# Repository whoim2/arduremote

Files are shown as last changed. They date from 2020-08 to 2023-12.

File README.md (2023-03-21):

# arduremote
ARDU Remote: simple USB / PPM (and SBUS in tests) RC radio controller transmitter 10 channels with QCZEK LRS

### updates:
21/03/2023 8 axes and 2 buttons in usb joystic mode, custom changes in ArduinoJoystickLibrary - download used_libs.zip!

### ВАЖНО:
If the equipment constantly beeps when turned on, this is due to high channel performance protection. You connected something incorrectly, or did not turn off important channels. You can enable SERIAL_DEBUG and evaluate channel values, or disable protection by setting started = true and check values otherwise.

Если аппаратура постоянно пищит при включении, это срабатывает защита от высоких показателей каналов. Вы что то подключили неправильно, или не выключили важные каналы. Вы можете включить SERIAL_DEBUG и оценить значения каналов, или отключить защиту установив started = true, и проверить значения иначе.

Based on arduino pro micro (atmega32u4), have h/w USB port for use as joystic in any OS.
Work with Open.HD.
Have simple calibrate procedure.
Have start protection and 30-secs warning if not used.

May work with QCZEK LRS and other, have PPM pin 8/10 channels.

QCZEK Project: http://qczek.beyondrc.com/qczek-lrs-433mhz-1w-lora-rc-link/

Low cost RC controller from old RC parts! 3D models present.



If you want use this only as usb joystic, you not need battery, power module, power switch and not need remove fuse on Arduino Pro Micro.
If you use PPM and LRS, you need set channels count in PPMEncoder.h to 10

=== SBUS TEST VERSION ===

QCZEK >=2.0 have only SBUS input. Try this sketch for it: https://github.com/whoim2/arduremote/blob/SBUS-test/ardu_remote.ino
Not need external inverter, but need resistors for down voltage from 5v to 3.3v. As for ppm pin on sheme. Connect TX pin arduino to RX pin qczek via resistors.

===

Video for russian users: https://youtu.be/x-7y0d95x8k
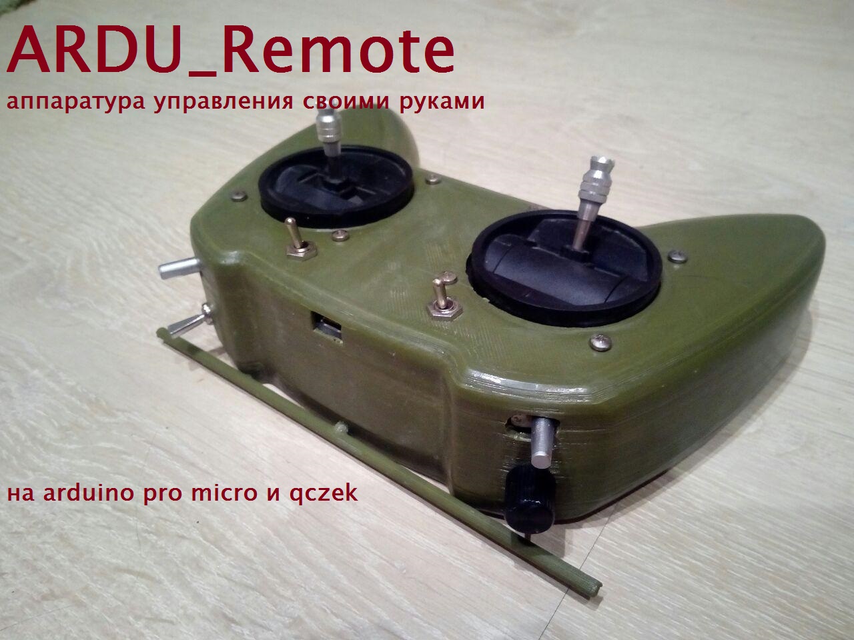
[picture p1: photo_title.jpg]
Watch the video (https://youtu.be/x-7y0d95x8k)


===

Build:
1) install Arduino IDE
2) copy folders from used_libs.zip to Arduino/libraries folder
3) open ardu_remote.ino in Arduino IDE, try to compile
4) connect Arduino Pro Micro to usb
5) select pro micro in tools/boards menu, press Upload button in IDE
6) solder all parts to Arduino, using sheme.bmp

===

For calibrate sticks & aux1, press calibrate button and power on, before set roll/pitch/yaw axis in zero position, trottle & aux1 set to minimum. While beeps, move sticks & aux1 from min to max positions.
If no beeps at time, power off device. Calibrate done.

Short beeps after power on - protection, channels value not in minimum. Off all switchs & move throttle to minimum.

===

You may connect jdy-30 / hc-05/06 bluetooth module to qczek and have mavlink telemetry on android device with "Droid Planner 2.8" or "Telemetry Vieawer" app. It work with Inav / mavlink.

Also, you may connect mavlink-display to QCZEK:
https://github.com/whoim2/mavlink-display

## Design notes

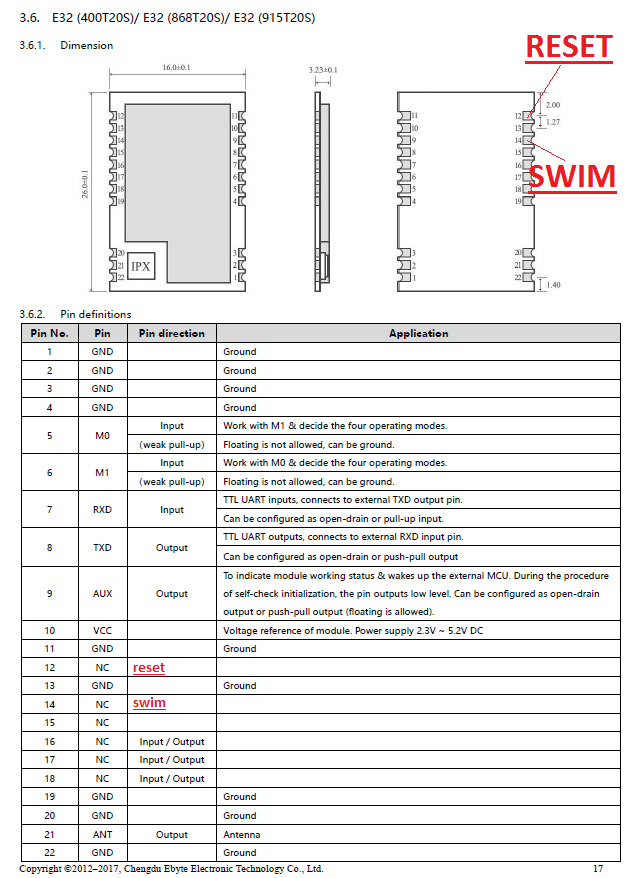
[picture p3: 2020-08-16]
915T20S.PNG

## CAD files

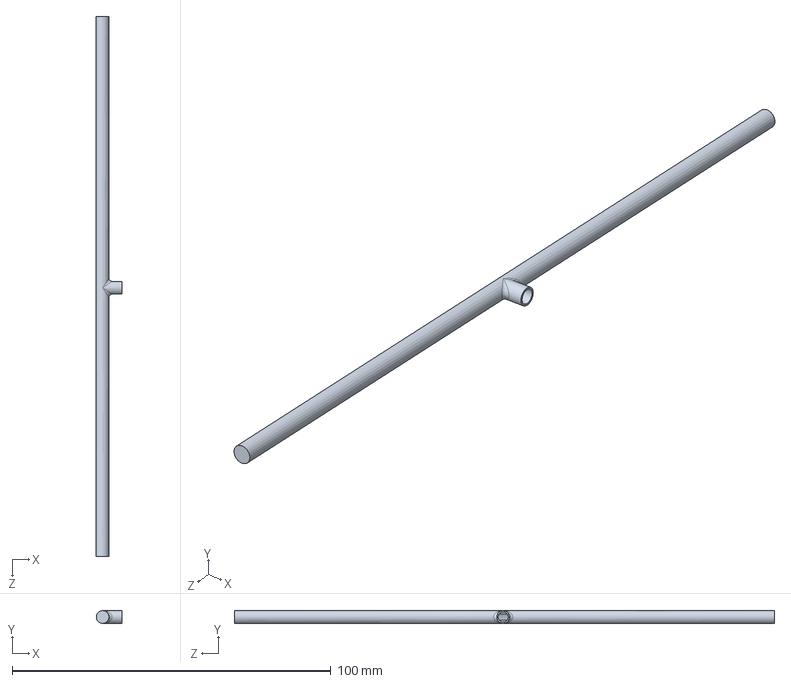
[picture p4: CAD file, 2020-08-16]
ant_868_full.SLDPRT
8.00 x 4.00 x 169.3 mm

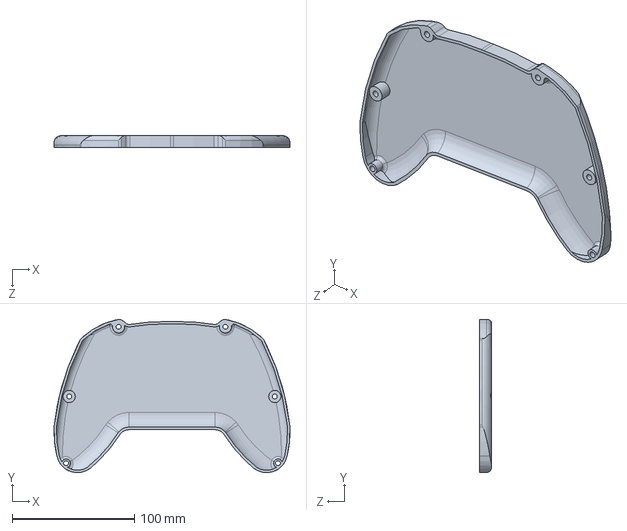
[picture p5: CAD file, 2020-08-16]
bottom.SLDPRT
193.2 x 125.4 x 10.0 mm

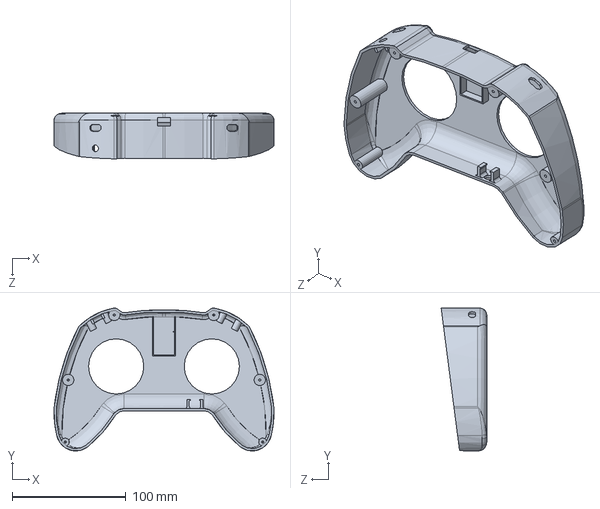
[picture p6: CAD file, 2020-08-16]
top.SLDPRT
193.2 x 125.4 x 40.0 mm

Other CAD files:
ant_868_full.STL
bottom.STL
top.STL

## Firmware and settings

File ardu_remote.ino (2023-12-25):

/* 
 ARDU_REMOTE
 usb / ppm simple remote
 whoim@mail.ru
*/

#include <EEPROM.h>
#include <JoystickMHX.h>
#include "PPMEncoder.h"

Joystick_ Joystick(JOYSTICK_DEFAULT_REPORT_ID,JOYSTICK_TYPE_JOYSTICK,
  32, 2,                  // Button Count, Hat Switch Count
  true, true, true,     // X and Y, Z Axis
  true, true, true,   // Rx, Ry,  Rz
  true, true, true, true,  // slider, dial, rudder and throttle
  false, false, false);  // accelerator, brake, and steering

//uncomment this for see states in port monitor, 9600bps
//usb joystic not work, comment for usb mode
//#define SERIAL_DEBUG

#define TRTL_PIN          A2
#define YAW_PIN           A3
#define PITCH_PIN         A1
#define ROLL_PIN          A0
#define SW1_PIN           6
#define SW2_PIN           4
#define SW3_1_PIN         7
#define SW3_2_PIN         8
#define SW4_PIN           16  //comment to disable
#define SW5_PIN           14  //comment to disable
#define AUX1_PIN          A10 //comment to disable

//
#define BUZZER_PIN        3
#define LED_PIN           2
#define SW_CALIBRATE_PIN  5

//PPM output, comment to disable
//#define PPM_PIN 9

//SBUS output, comment to disable (tx pin of serial)
//#define SBUS

//UART output for jdy-40/41
#define UART

//non-use beep timer millis, comment to disable
//#define NTIM 30000


// sbus settings
#define RC_CHANNEL_MIN 990
#define RC_CHANNEL_MAX 2010

#define SBUS_MIN_OFFSET 173
#define SBUS_MID_OFFSET 992
#define SBUS_MAX_OFFSET 1811
#define SBUS_CHANNEL_NUMBER 16
#define SBUS_PACKET_LENGTH 25
#define SBUS_FRAME_HEADER 0x0f
#define SBUS_FRAME_FOOTER 0x00
#define SBUS_FRAME_FOOTER_V2 0x04
#define SBUS_STATE_FAILSAFE 0x08
#define SBUS_STATE_SIGNALLOSS 0x04
#define SBUS_UPDATE_RATE 10 //ms

//
#define UART_UPDATE_RATE 20 //ms

//sketch
bool started = false;

//calibrate vars
int rollmax, rollmin, rollzero;
int pitchmax, pitchmin, pitchzero;
int yawmax, yawmin, yawzero;
int throttlemax, throttlemin;
#ifdef AUX1_PIN
int aux1max,aux1min;
#endif
uint32_t joyTime = 0;
#define JOY_UPDATE_RATE 15 //ms

uint8_t ch13_val = 0;
uint8_t ch14_val = 0;
uint8_t ch15_val = 0;

#ifdef NTIM
uint32_t prevtimer = millis();
int16_t prev_ch_crc;
#endif

#ifdef SBUS
uint8_t sbusPacket[SBUS_PACKET_LENGTH];
int rcChannels[SBUS_CHANNEL_NUMBER];
uint32_t sbusTime = 0;
#endif

#ifdef UART
uint32_t uartTime = 0;
#endif

//********* FUNCTIONS ***********
void EEPROM_int_write(int addr, int num) {
  byte raw[2];
  (int&)raw = num;
  for(byte i = 0; i < 2; i++) EEPROM.write(addr+i, raw[i]);
}
int EEPROM_int_read(int addr) {    
  byte raw[2];
  for(byte i = 0; i < 2; i++) raw[i] = EEPROM.read(addr+i);
  int &num = (int&)raw;
  return num;
}

void beep(uint16_t time) {
  digitalWrite(LED_PIN, LOW);
  tone(BUZZER_PIN, 1000);
  delay(time / 10);
  noTone(BUZZER_PIN);
  digitalWrite(LED_PIN, HIGH);
}

//sbus functions
void sbusPreparePacket(uint8_t packet[], int channels[], bool isSignalLoss, bool isFailsafe){

    static int output[SBUS_CHANNEL_NUMBER] = {0};

    /*
     * Map 1000-2000 with middle at 1500 chanel values to
     * 173-1811 with middle at 992 S.BUS protocol requires
     */
    for (uint8_t i = 0; i < SBUS_CHANNEL_NUMBER; i++) {
        output[i] = map(channels[i], RC_CHANNEL_MIN, RC_CHANNEL_MAX, SBUS_MIN_OFFSET, SBUS_MAX_OFFSET);
    }

    uint8_t stateByte = 0x00;
    if (isSignalLoss) {
        stateByte |= SBUS_STATE_SIGNALLOSS;
    }
    if (isFailsafe) {
        stateByte |= SBUS_STATE_FAILSAFE;
    }
    packet[0] = SBUS_FRAME_HEADER; //Header 

    packet[1] = (uint8_t) (output[0] & 0x07FF);
    packet[2] = (uint8_t) ((output[0] & 0x07FF)>>8 | (output[1] & 0x07FF)<<3);
    packet[3] = (uint8_t) ((output[1] & 0x07FF)>>5 | (output[2] & 0x07FF)<<6);
    packet[4] = (uint8_t) ((output[2] & 0x07FF)>>2);
    packet[5] = (uint8_t) ((output[2] & 0x07FF)>>10 | (output[3] & 0x07FF)<<1);
    packet[6] = (uint8_t) ((output[3] & 0x07FF)>>7 | (output[4] & 0x07FF)<<4);
    packet[7] = (uint8_t) ((output[4] & 0x07FF)>>4 | (output[5] & 0x07FF)<<7);
    packet[8] = (uint8_t) ((output[5] & 0x07FF)>>1);
    packet[9] = (uint8_t) ((output[5] & 0x07FF)>>9 | (output[6] & 0x07FF)<<2);
    packet[10] = (uint8_t) ((output[6] & 0x07FF)>>6 | (output[7] & 0x07FF)<<5);
    packet[11] = (uint8_t) ((output[7] & 0x07FF)>>3);
    packet[12] = (uint8_t) ((output[8] & 0x07FF));
    packet[13] = (uint8_t) ((output[8] & 0x07FF)>>8 | (output[9] & 0x07FF)<<3);
    packet[14] = (uint8_t) ((output[9] & 0x07FF)>>5 | (output[10] & 0x07FF)<<6);  
    packet[15] = (uint8_t) ((output[10] & 0x07FF)>>2);
    packet[16] = (uint8_t) ((output[10] & 0x07FF)>>10 | (output[11] & 0x07FF)<<1);
    packet[17] = (uint8_t) ((output[11] & 0x07FF)>>7 | (output[12] & 0x07FF)<<4);
    packet[18] = (uint8_t) ((output[12] & 0x07FF)>>4 | (output[13] & 0x07FF)<<7);
    packet[19] = (uint8_t) ((output[13] & 0x07FF)>>1);
    packet[20] = (uint8_t) ((output[13] & 0x07FF)>>9 | (output[14] & 0x07FF)<<2);
    packet[21] = (uint8_t) ((output[14] & 0x07FF)>>6 | (output[15] & 0x07FF)<<5);
    packet[22] = (uint8_t) ((output[15] & 0x07FF)>>3);

    packet[23] = stateByte; //Flags byte
    packet[24] = SBUS_FRAME_FOOTER; //Footer
}

//********* SETUP ***********
void setup() {
  
  //serial
  #ifdef SERIAL_DEBUG //if debug
    Serial.begin(115200);
  #else
    Joystick.begin();
    
    Joystick.setXAxisRange(-127, 127);
    Joystick.setYAxisRange(-127, 127);
    Joystick.setZAxisRange(-127, 127);
    Joystick.setRxAxisRange(-127, 127);
    Joystick.setRyAxisRange(-127, 127);
    Joystick.setRzAxisRange(-127, 127);
    Joystick.setSliderRange(0, 255);
    Joystick.setDialRange(0, 255);
    Joystick.setRudderRange(0, 255);
    Joystick.setThrottleRange(0, 255);

    Joystick.setRudder(127);
    Joystick.setAccelerator(127);
    Joystick.setBrake(127);
    Joystick.setSteering(127);
  #endif

  //pins
  pinMode(SW1_PIN, INPUT_PULLUP);
  pinMode(SW2_PIN, INPUT_PULLUP);
  pinMode(SW3_1_PIN, INPUT_PULLUP);
  pinMode(SW3_2_PIN, INPUT_PULLUP);
  #ifdef SW4_PIN
  pinMode(SW4_PIN, INPUT_PULLUP);
  #endif
  #ifdef SW5_PIN
  pinMode(SW5_PIN, INPUT_PULLUP);
  #endif
  pinMode(SW_CALIBRATE_PIN, INPUT_PULLUP);
  
  pinMode(BUZZER_PIN, OUTPUT);
  pinMode(LED_PIN, OUTPUT);

  //ppm
  #ifdef PPM_PIN
    ppmEncoder.begin(PPM_PIN);
  #endif

  //sbus
  #ifdef SBUS
  for (uint8_t i = 0; i < SBUS_CHANNEL_NUMBER; i++) {
      rcChannels[i] = 1500;
  }
  Serial1.begin(100000, SERIAL_8E2);
  #endif

  //uart
  #ifdef UART
  Serial1.begin(38400); //jdy-41 baud
  #endif
  
  //start led
  digitalWrite(LED_PIN, HIGH);
  delay(100);
  //calibration at button
  if(digitalRead(SW_CALIBRATE_PIN) == LOW) {
    delay(500);
      beep(1000);
      #ifdef SERIAL_DEBUG
        Serial.println(F("Calibrate starting"));
      #endif
      //null & min position
      rollzero = round((analogRead(ROLL_PIN) + 0.5) / 10) * 10;
      rollmin = rollzero;
      EEPROM_int_write(2, rollzero);
      EEPROM_int_write(14, rollmin);
      
      pitchzero = round((analogRead(PITCH_PIN) + 0.5) / 10) * 10;
      pitchmin = pitchzero;
      EEPROM_int_write(6, pitchzero);
      EEPROM_int_write(22, pitchmin);
      
      yawzero = round((analogRead(YAW_PIN) + 0.5) / 10) * 10;
      yawmin = yawzero;
      EEPROM_int_write(10, yawzero);
      EEPROM_int_write(30, yawmin);
      
      throttlemin = analogRead(TRTL_PIN);
      EEPROM_int_write(38, throttlemin);

      aux1min = analogRead(AUX1_PIN);
      EEPROM_int_write(46, aux1min);
    
      while(1) { //min and max positions
        #ifdef SERIAL_DEBUG
          Serial.println(F("New calibrate data"));
        #endif
        //roll
        if(analogRead(ROLL_PIN) < rollmin) {
           rollmin = analogRead(ROLL_PIN);
           EEPROM_int_write(14, rollmin);
           beep(20);
        }
        if(analogRead(ROLL_PIN) > rollmax) {
           rollmax = analogRead(ROLL_PIN);
           EEPROM_int_write(18, rollmax);
           beep(20);
        }
        //pitch
        if(analogRead(PITCH_PIN) < pitchmin) {
           pitchmin = analogRead(PITCH_PIN);
           EEPROM_int_write(22, pitchmin);
           beep(20);
        }
        if(analogRead(PITCH_PIN) > pitchmax) {
           pitchmax = analogRead(PITCH_PIN);
           EEPROM_int_write(26, pitchmax);
           beep(20);
        }
        //yaw
        if(analogRead(YAW_PIN) < yawmin) {
           yawmin = analogRead(YAW_PIN);
           EEPROM_int_write(30, yawmin);
           beep(20);
        }
        if(analogRead(YAW_PIN) > yawmax) {
           yawmax = analogRead(YAW_PIN);
           EEPROM_int_write(34, yawmax);
           beep(20);
        }
        //throttle
        if(analogRead(TRTL_PIN) < throttlemin) {
           throttlemin = analogRead(TRTL_PIN);
           EEPROM_int_write(38, throttlemin);
           beep(20);
        }
        if(analogRead(TRTL_PIN) > throttlemax) {
           throttlemax = analogRead(TRTL_PIN);
           EEPROM_int_write(42, throttlemax);
           beep(20);
        }
        //aux1
        if(analogRead(AUX1_PIN) < aux1min) {
           aux1min = analogRead(AUX1_PIN);
           EEPROM_int_write(46, aux1min);
           beep(20);
        }
        if(analogRead(AUX1_PIN) > aux1max) {
           aux1max = analogRead(AUX1_PIN);
           EEPROM_int_write(50, aux1max);
           beep(20);
        }

        //debug
        #ifdef SERIAL_DEBUG
          Serial.print("CAL# ");
          Serial.print("R: " + String(rollmin) + " < " + String(rollzero) + " > " + String(rollmax));
          Serial.print("\tP: " + String(pitchmin) + " < " + String(pitchzero) + " > " + String(pitchmax));
          Serial.print("\tT: " + String(throttlemin) + " <> " + String(throttlemax));
          Serial.print("\tY: " + String(yawmin) + " < " + String(yawzero) + " > " + String(yawmax));
          Serial.print("\tA1: " + String(aux1min) + " <> " + String(aux1max));
          Serial.println();
        #endif

        delay(200);
        
      }//while 1
  }//calibration

  //read calibration data
  rollzero =  EEPROM_int_read(2);
  pitchzero = EEPROM_int_read(6);
  yawzero =  EEPROM_int_read(10);
  rollmin =   EEPROM_int_read(14);
  rollmax =   EEPROM_int_read(18);
  pitchmin =  EEPROM_int_read(22);
  pitchmax =  EEPROM_int_read(26);
  yawmin =   EEPROM_int_read(30);
  yawmax =   EEPROM_int_read(34);
  throttlemin =  EEPROM_int_read(38);
  throttlemax =  EEPROM_int_read(42);
  aux1min =  EEPROM_int_read(46);
  aux1max =  EEPROM_int_read(50);

  #ifdef SERIAL_DEBUG
    beep(100);
    delay(3000);
    Serial.println("CALIBRATION DATA");
    Serial.print("R: " + String(rollmin) + " < " + String(rollzero) + " > " + String(rollmax));
    Serial.print("\tP: " + String(pitchmin) + " < " + String(pitchzero) + " > " + String(pitchmax));
    Serial.print("\tT: " + String(throttlemin) + " <> " + String(throttlemax));
    Serial.print("\tY: " + String(yawmin) + " < " + String(yawzero) + " > " + String(yawmax));
    #ifdef AUX1_PIN
    Serial.print("\tA1: " + String(aux1min) + " <> " + String(aux1max));
    #endif
    Serial.println();

    #ifdef PPM_PIN
    Serial.println("mode PPM");
    #endif
    #ifdef SBUS
    Serial.println("mode SBUS");
    #endif
    #ifdef UART
    Serial.println("mode UART");
    #endif
      
    delay(3000);
  #endif
}

//********* LOOP ***********
void loop() {
  uint32_t currentMillis = millis();
  
  #ifdef NTIM
    int16_t ch_crc = 0; 
  #endif
  
  //roll
  int8_t roll = 0;
  if( round((analogRead(ROLL_PIN) + 0.5) / 10) * 10 != rollzero )  roll = map(analogRead(ROLL_PIN),rollmin,rollmax,-127,127);
  #ifdef NTIM
    ch_crc += roll; 
  #endif
  //pitch
  int8_t pitch = 0;
  if( round((analogRead(PITCH_PIN) + 0.5) / 10) * 10 != pitchzero)  pitch = map(analogRead(PITCH_PIN),pitchmin,pitchmax,-127,127);
  #ifdef NTIM
    ch_crc += pitch; 
  #endif
  //yaw
  int8_t yaw = 0;
  if( round((analogRead(YAW_PIN) + 0.5) / 10) * 10 != yawzero) yaw = map(analogRead(YAW_PIN),yawmin,yawmax,-127,127);
  #ifdef NTIM
    ch_crc += yaw; 
  #endif
  //throttle
  uint8_t throttle = map(analogRead(TRTL_PIN),throttlemin,throttlemax,0,255);
  #ifdef NTIM
    ch_crc += throttle; 
  #endif
  //sw1
  uint8_t sw1 = 0;
  if(digitalRead(SW1_PIN) == LOW) sw1 = 255;
  #ifdef NTIM
    ch_crc += sw1+20; 
  #endif
  //sw2
  uint8_t sw2 = 0;
  if(digitalRead(SW2_PIN) == LOW) sw2 = 255;
  #ifdef NTIM
    ch_crc += sw2+30; 
  #endif
  //sw3
  uint8_t sw3 = 0;
  if(digitalRead(SW3_1_PIN) == HIGH && digitalRead(SW3_2_PIN) == HIGH) sw3 = 127;
  else if (digitalRead(SW3_1_PIN) == LOW && digitalRead(SW3_2_PIN) == HIGH) sw3 = 255;
  #ifdef NTIM
    ch_crc += sw3+40; 
  #endif
  //sw4
  #ifdef SW4_PIN
    uint8_t sw4 = 0;
    if(digitalRead(SW4_PIN) == LOW) sw4 = 255;
    #ifdef NTIM
      ch_crc += sw4+50; 
    #endif
  #endif
  //sw5
  #ifdef SW5_PIN
    uint8_t sw5 = 0;
    if(digitalRead(SW5_PIN) == LOW) sw5 = 255;
    #ifdef NTIM
      ch_crc += sw5+60; 
    #endif
  #endif
  //aux1
  #ifdef AUX1_PIN
    uint8_t aux1 = map(analogRead(AUX1_PIN),aux1min,aux1max,0,255);
    #ifdef NTIM
      ch_crc += aux1; 
    #endif
  #endif
  if(digitalRead(SW_CALIBRATE_PIN) == LOW) {
    if(yaw < -100) { //yaw left and calibrate swap racemode
      beep(100);
      if(ch14_val == 0) { ch14_val = 255; delay(50); beep(100); }
      else ch14_val = 0;
    }
    else if(yaw > 100) { //yaw right set power as trottle
      beep(100);
      ch15_val = throttle;
    }
    else {
      beep(100);
      if(ch13_val == 0) { ch13_val = 255; delay(50); beep(100); }
      else ch13_val = 0;
    }
    delay(300);
  }
  //startup protection
  if(!started) {
      if(throttle<10 && sw1==0 && sw2==0 && sw3==0 && sw4==0 && sw5==0) {
        started = true;
        //start short beep
        beep(200);
      }
      else {
        beep(50);
        delay(300);
      }
  } else {
    #ifdef SERIAL_DEBUG
      /* //uncomment for see raw rounded values
       * Serial.print("R_raw: " + String(round((analogRead(ROLL_PIN) + 0.5) / 10) * 10));
      Serial.print("\tP_raw: " + String(round((analogRead(PITCH_PIN) + 0.5) / 10) * 10));
      Serial.print("\tT_raw: " + String(map(analogRead(TRTL_PIN),throttlemin,throttlemax,0,255)));
      Serial.print("\tY_raw: " + String(round((analogRead(YAW_PIN) + 0.5) / 10) * 10));
      #ifdef AUX1_PIN
      Serial.print("\tA1_raw: " + String(map(analogRead(AUX1_PIN),aux1min,aux1max,0,255)));
      #endif
      Serial.println();
      */
      Serial.print("R: " + String(roll));
      Serial.print("\tP: " + String(pitch));
      Serial.print("\tT: " + String(throttle));
      Serial.print("\tY: " + String(yaw));
      Serial.print("\tS1: " + String(sw1));
      Serial.print("\tS2: " + String(sw2));
      Serial.print("\tS3: " + String(sw3));
      #ifdef SW4_PIN
      Serial.print("\tS4: " + String(sw4));
      #endif
      #ifdef SW5_PIN
      Serial.print("\tS5: " + String(sw5));
      #endif
      #ifdef AUX1_PIN
      Serial.print("\tA1: " + String(aux1));
      #endif
      Serial.println();
      
      delay(200);
    #else //no debug
      //sticks
      Joystick.setXAxis(roll);
      Joystick.setYAxis(pitch);
      Joystick.setZAxis(throttle-127);
      Joystick.setRxAxis(yaw);
      
      //for pc/games (use setbutton)
      /*
      Joystick.setButton(0,sw1);
      Joystick.setButton(1,sw2);
      Joystick.setRyAxis(sw3);
      Joystick.setButton(2,sw4);
      Joystick.setButton(3,sw5);
      Joystick.setRzAxis((aux1+127)*1.411);
      */
      //for open.hd (max use axis)
      Joystick.setRyAxis(sw1*1.411);
      Joystick.setRzAxis(sw2*1.411);
      Joystick.setSlider(sw3);
      #ifdef SW4_PIN
      //Joystick.setButton(0,sw4);
      Joystick.setRudder(sw4);
      #endif
      #ifdef SW5_PIN
      //Joystick.setButton(1,sw5);
      Joystick.setThrottle(sw5);
      #endif
      #ifdef AUX1_PIN
      Joystick.setDial(aux1);
      #endif
      if (currentMillis > joyTime) {
          Joystick.sendState();
          joyTime = currentMillis + JOY_UPDATE_RATE;
      }
      
    #endif //debug

    //ppm
    #ifdef PPM_PIN
      //axis
      ppmEncoder.setChannel(0, 1000+(roll+127)*3.937);
      ppmEncoder.setChannel(1, 1000+(pitch+127)*3.937);
      ppmEncoder.setChannel(2, 1000+throttle*3.922);
      ppmEncoder.setChannel(3, 1000+(yaw+127)*3.937);
      //sw
      ppmEncoder.setChannel(4, 1000+sw1*3.922);
      ppmEncoder.setChannel(5, 1000+sw2*3.922);
      ppmEncoder.setChannel(6, 1000+sw3*3.922);
      #ifdef SW4_PIN
      ppmEncoder.setChannel(7, 1000+sw4*3.922);
      #endif
      #ifdef SW5_PIN
      ppmEncoder.setChannel(8, 1000+sw5*3.922);
      #endif
      //aux
      #ifdef AUX1_PIN
      ppmEncoder.setChannel(9, 1000+aux1*3.922);
      #endif
    #endif //ppm
    //sbus
    #ifdef SBUS
      //axis
      rcChannels[0] = 1003+(roll+127)*3.937;
      rcChannels[1] = 1003+(pitch+127)*3.937;
      rcChannels[2] = 1003+throttle*3.922;
      rcChannels[3] = 1003+(yaw+127)*3.937;
      //sw
      rcChannels[4] = 1003+sw1*3.922;
      rcChannels[5] = 1003+sw2*3.922;
      rcChannels[6] = 1003+sw3*3.922;
      #ifdef SW4_PIN
      rcChannels[7] = 1003+sw4*3.937;
      #endif
      #ifdef SW5_PIN
      rcChannels[8] = 1003+sw5*3.922;
      #endif
      //aux
      #ifdef AUX1_PIN
      rcChannels[9] = 1003+aux1*3.922;
      #endif
      //fill min
      rcChannels[10] = 1003;
      rcChannels[11] = 1003;
      //qczek settings for 2.1
      rcChannels[12] = ch13_val;
      rcChannels[13] = ch14_val; //14
      rcChannels[14] = ch15_val; //15ch
      
    if (currentMillis > sbusTime) {
        sbusPreparePacket(sbusPacket, rcChannels, false, false);
        Serial1.write(sbusPacket, SBUS_PACKET_LENGTH);
        sbusTime = currentMillis + SBUS_UPDATE_RATE;
    }
    #endif //sbus
    #ifdef UART
    byte uart_data[18] = {
      (uint8_t)0x15,
      (uint8_t)0x37,
      (uint8_t)0xFA,
      (int8_t)roll,
      (int8_t)pitch,
      (uint8_t)throttle,
      (int8_t)yaw,
      (uint8_t)sw1,
      (uint8_t)sw2,
      (uint8_t)sw3,
      (uint8_t)sw4,
      (uint8_t)sw5,
      (uint8_t)aux1,
      (uint8_t)0,
      (uint8_t)0,
      (uint8_t)ch13_val,
      (uint8_t)ch14_val,
      (uint8_t)ch15_val,
      };
    if (currentMillis > uartTime) {
        Serial1.write(uart_data, 18);
        uartTime = currentMillis + UART_UPDATE_RATE;
    }
    #endif //uart
  } //debug
  #ifdef NTIM
  if((prevtimer + NTIM) < millis()) {
      prevtimer = millis();
      if(ch_crc == prev_ch_crc) beep(10);
      prev_ch_crc = ch_crc;
  }
  #endif //ntim
}

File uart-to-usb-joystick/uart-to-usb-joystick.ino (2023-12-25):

#include <JoystickMHX.h>

//#define SERIAL_DEBUG
#define JOY_UPDATE_RATE 15 //ms

//Joystic settings
Joystick_ Joystick(JOYSTICK_DEFAULT_REPORT_ID,JOYSTICK_TYPE_JOYSTICK,
  32, 2,                  // Button Count, Hat Switch Count
  true, true, true,     // X and Y, Z Axis
  true, true, true,   // Rx, Ry,  Rz
  true, true, true, true,  // slider, dial, rudder and throttle
  false, false, false);  // accelerator, brake, and steering

byte data[18];
uint32_t joyTime = 0;
uint8_t pos=0;

void setup() {
  #ifdef SERIAL_DEBUG
  Serial.begin(115200);
  while (!Serial) {}
  Serial.println("Started");
  #else
  Joystick.begin();
  //range
  Joystick.setXAxisRange(-127, 127);
  Joystick.setYAxisRange(-127, 127);
  Joystick.setZAxisRange(-127, 127);
  Joystick.setRxAxisRange(-127, 127);
  Joystick.setRyAxisRange(-127, 127);
  Joystick.setRzAxisRange(-127, 127);
  Joystick.setSliderRange(0, 255);
  Joystick.setDialRange(0, 255);
  Joystick.setRudderRange(0, 255);
  Joystick.setThrottleRange(0, 255);
  //default
  Joystick.setRudder(127);
  Joystick.setAccelerator(127);
  Joystick.setBrake(127);
  Joystick.setSteering(127);
  #endif
  Serial1.begin(38400); //jdy-41 baud
  while (!Serial1) {}
  Serial.println("uart started");
}

void loop() {
  if (Serial1.available()) {
   data[pos] = Serial1.read();
   pos++;
   if(pos > 17) pos=0;

   //sync
   if(pos > 1) {
    if((uint8_t)data[pos-2] == 0x15 && (uint8_t)data[pos-1] == 0x37 && (uint8_t)data[pos] == 0xFA) { pos=2; }
   }
  }
  if (millis() > joyTime) {
   #ifdef SERIAL_DEBUG
   for (uint8_t i = 0; i<18; i++) {
     Serial.print(i);
     Serial.print(":");
     if(i==3 || i==4 || i==6) Serial.print((int8_t)data[i]);
     else Serial.print((uint8_t)data[i]);
     Serial.print("\t");
   }
   Serial.println();
   #else
   Joystick.setXAxis    ((int8_t)data[3]);
   Joystick.setYAxis    ((int8_t)data[4]);
   Joystick.setZAxis    ((uint8_t)data[5]-127);
   Joystick.setRxAxis   ((int8_t)data[6]);
   Joystick.setRyAxis   ((uint8_t)data[7]);
   Joystick.setRzAxis   ((uint8_t)data[8]);
   Joystick.setSlider   ((uint8_t)data[9]);
   Joystick.setRudder   ((uint8_t)data[10]);
   Joystick.setThrottle ((uint8_t)data[11]);
   Joystick.setDial     ((uint8_t)data[12]);
   Joystick.sendState();
   joyTime = millis() + JOY_UPDATE_RATE;
   #endif
  }
}
